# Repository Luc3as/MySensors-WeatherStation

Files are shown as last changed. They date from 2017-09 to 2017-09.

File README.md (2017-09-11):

# MySensors-WeatherStation
Weather station based on arduino and MySensors

It is battery operated, solar pannel charged, wirelessly communicating weather station which can measure temperature, humidity, moisture,  atmospheric pressure and rain.

Body of weather station is partly 3d printed and each radiation shield floor is made of pot plate you can get in garden supplies.
There are 3D printables files, as well as source files from Autodesk Invetor if you need to adjust some parts.

## Final installation

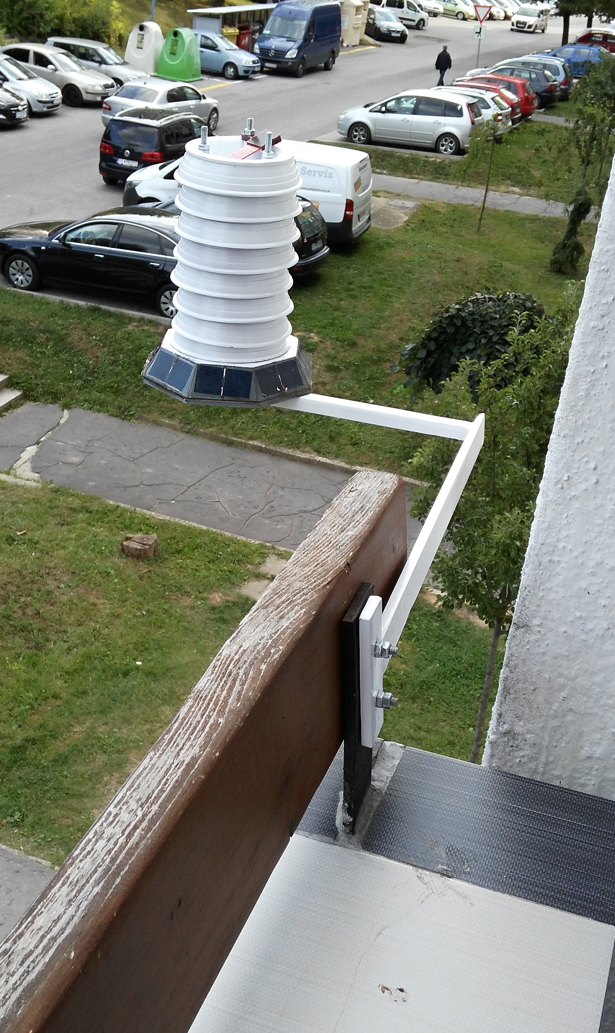
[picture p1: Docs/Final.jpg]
Final installation


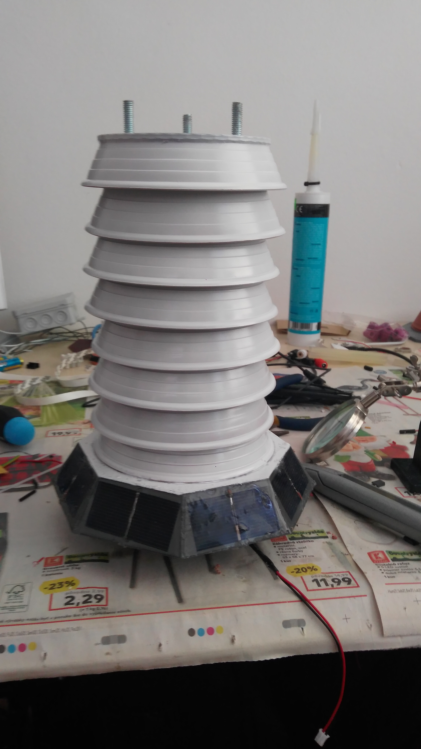
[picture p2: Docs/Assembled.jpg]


## From protype to functional weather station

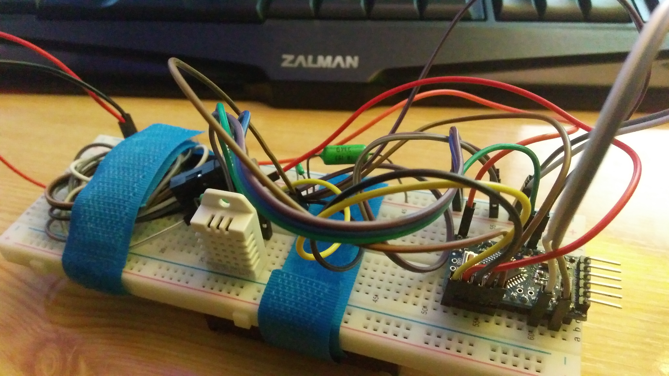
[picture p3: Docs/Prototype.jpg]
Prototype


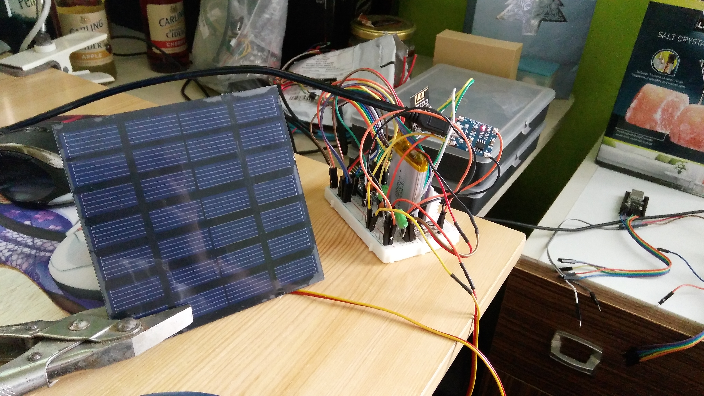
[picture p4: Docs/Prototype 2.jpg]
Prototype 2


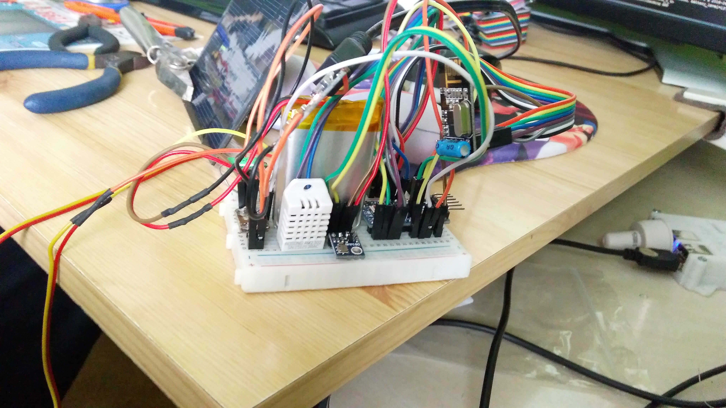
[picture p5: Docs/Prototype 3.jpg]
Prototype3


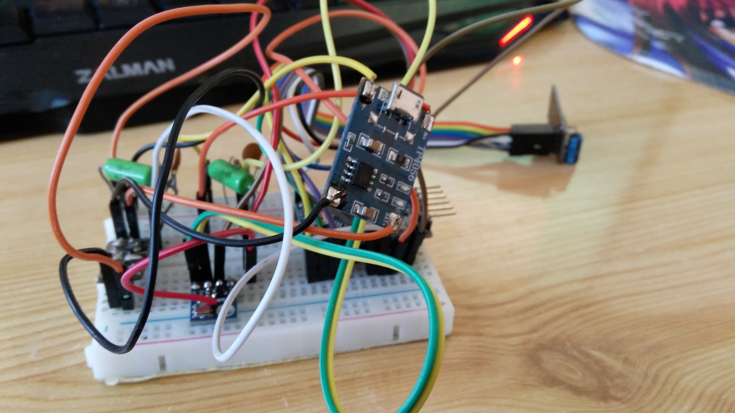
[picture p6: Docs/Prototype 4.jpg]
Prototype 4


I started with breadboard, attached arduino pro mini, NRF24 some DHT22 temp meter and do some basic code.
Later I added solar pannel, with charging contoller, LiPo battery, and voltage level convertor to do voltage measurement of battery and solar pannel.

Later I replaced DHT22 sensor with Si 7021 which provides better performance and reliability by my experience.

## PCBs

Prototype was working so I started designing PCBS in Fritzing, you can find source file in PCB folder. About month from ordering at chinese website, manufactured PCBs arrived.

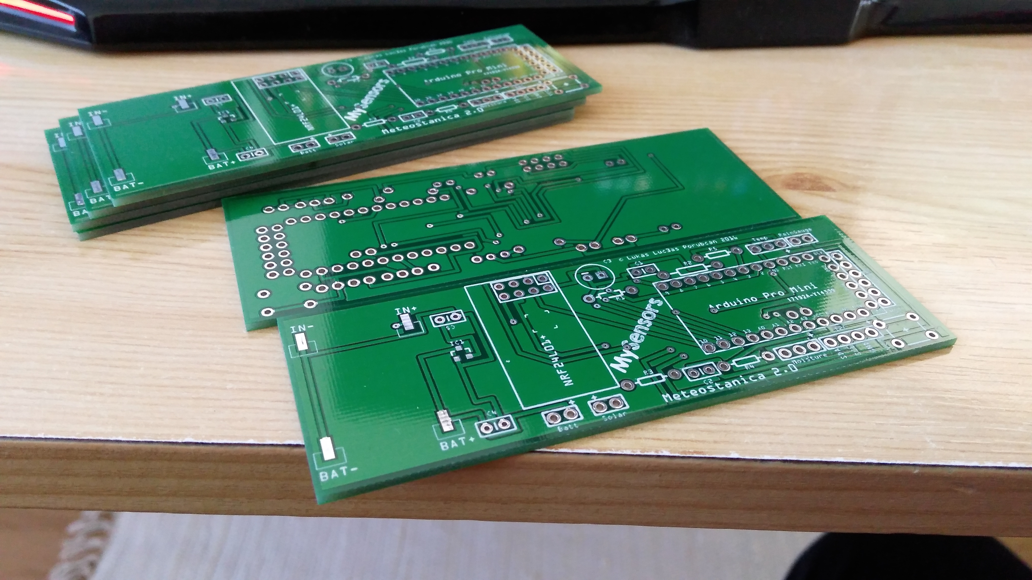
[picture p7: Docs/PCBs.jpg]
PCBs


I was very curious if my design will work so I started assembly of PCB very quickly.

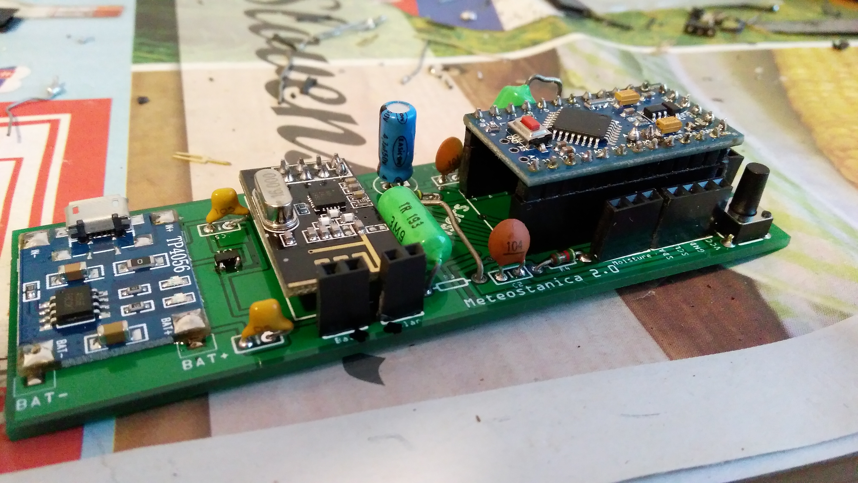
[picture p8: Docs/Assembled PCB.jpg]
PCBs assembled


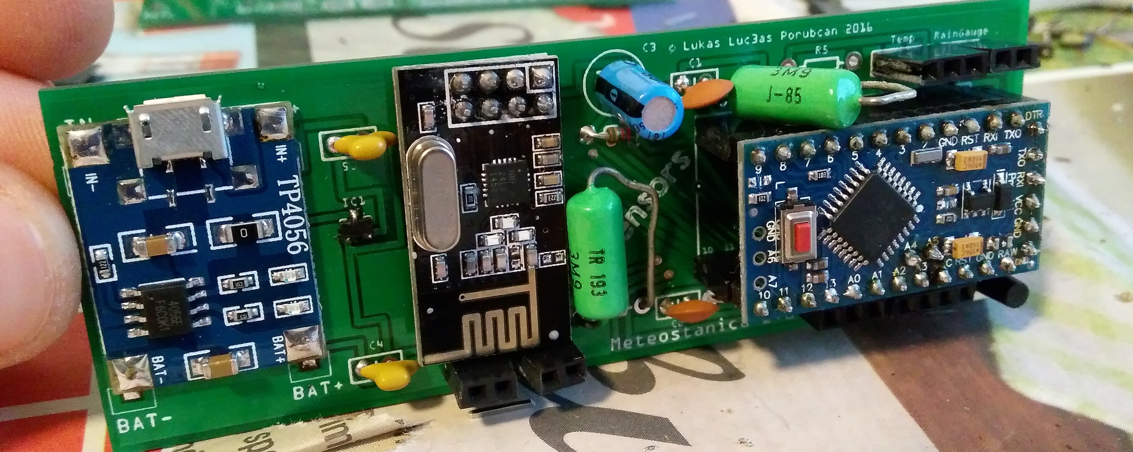
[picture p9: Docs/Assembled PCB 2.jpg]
PCBs assembled 2


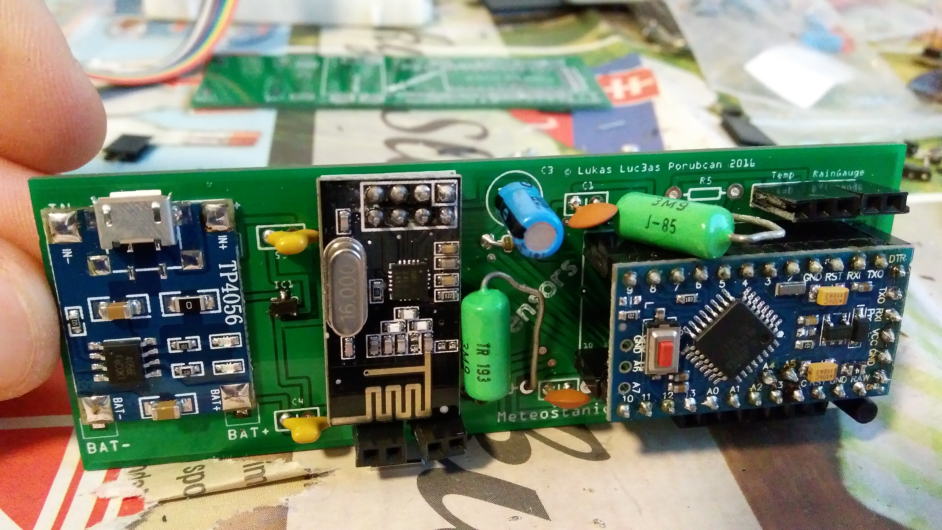
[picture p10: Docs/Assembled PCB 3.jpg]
PCBs assembled 3


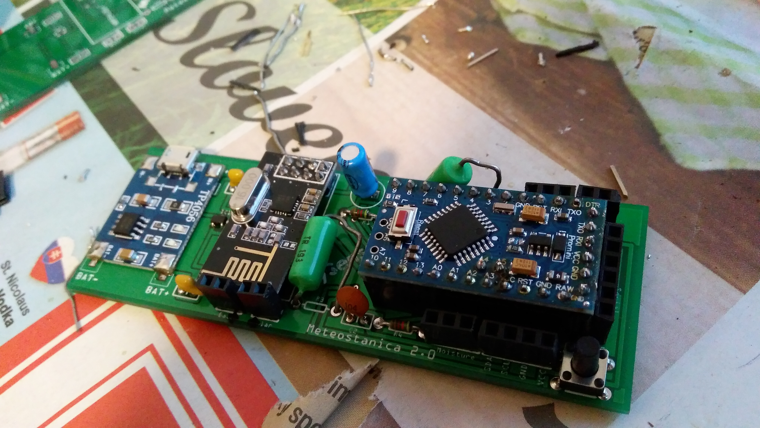
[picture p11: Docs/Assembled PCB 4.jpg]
PCBs assembled 4


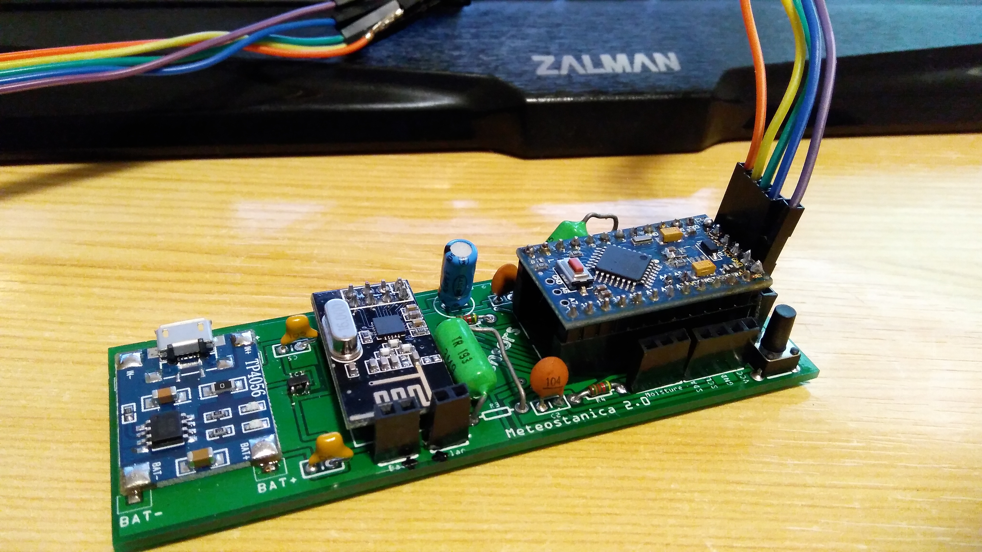
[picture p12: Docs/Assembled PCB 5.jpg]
PCBs assembled 5


## Building the body

I printed the base of weather station and started to assembly solar pannels which are glued in clear epoxy resin. I have to lay each side of base absolutely flat, put panel with wires in little window on sides, and after puoring the epoxy resin wait till it harden.
In next designs I would choose another path and probably made each pannel shell separate so I can glue all panels at once and when they will be hard and more durable I would glue it to the base.

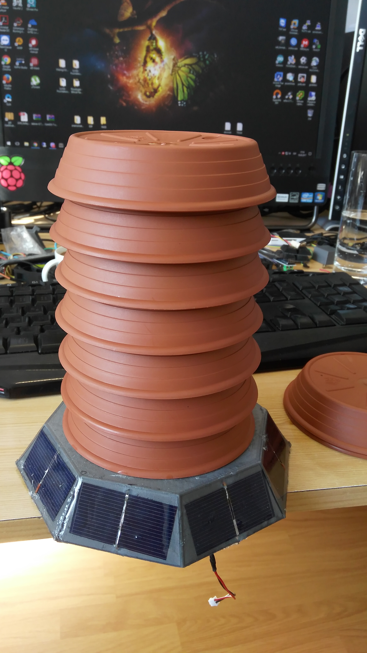
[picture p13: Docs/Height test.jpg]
Heigh test of stands


All the pannels are connected in serie, providing about 4,5V in direct sunlight, which is enough to charge the battery every day.

For holding all together there are 3x 6mm rods which goes through every floor and are secured with nuts. All holes are secured with silicon providing little of waterproofness mainly for sensors and for base where electronics is localed.

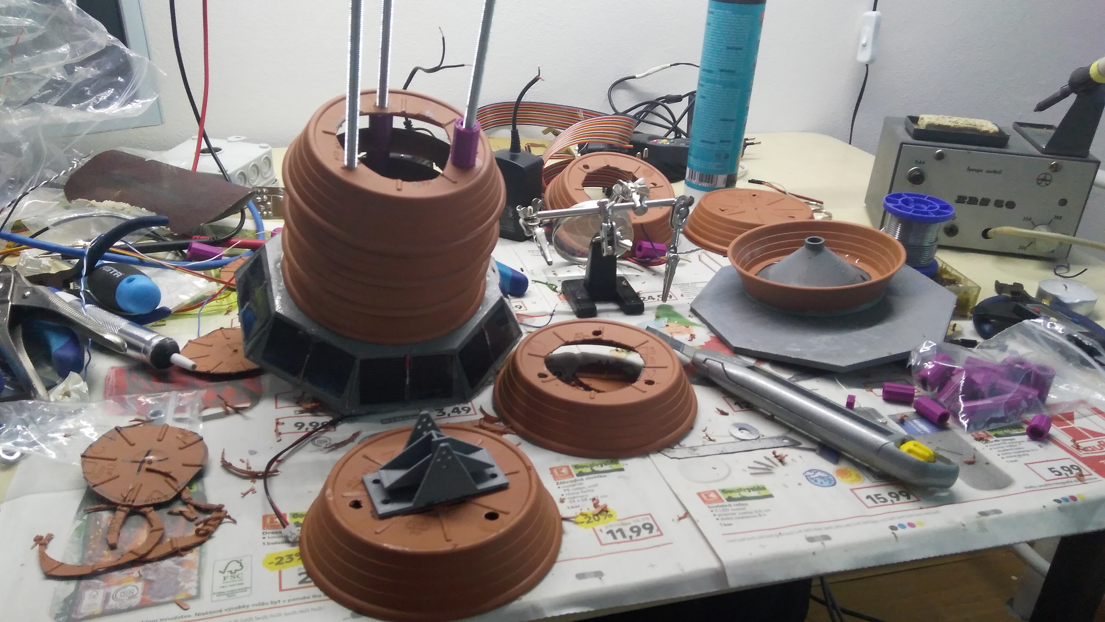
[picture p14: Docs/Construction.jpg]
Construction


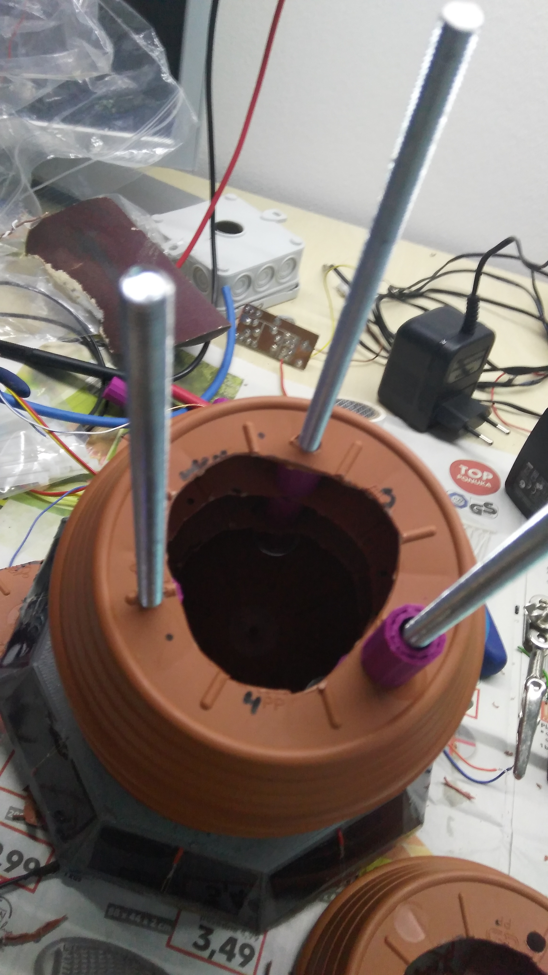
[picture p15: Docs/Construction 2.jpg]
Construction


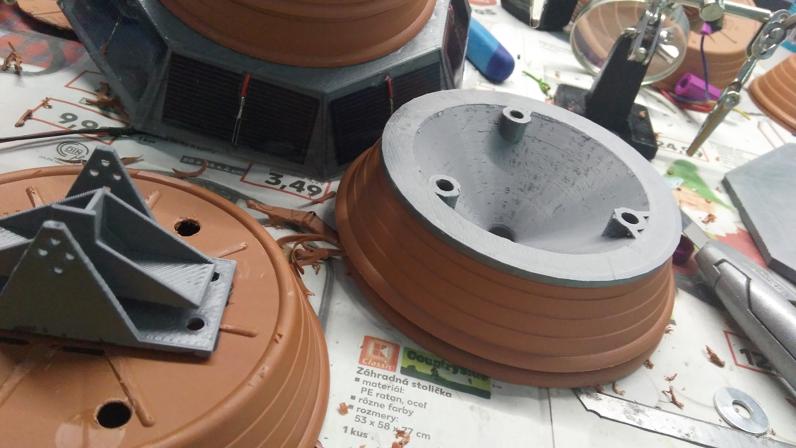
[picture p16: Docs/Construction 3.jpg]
Construction


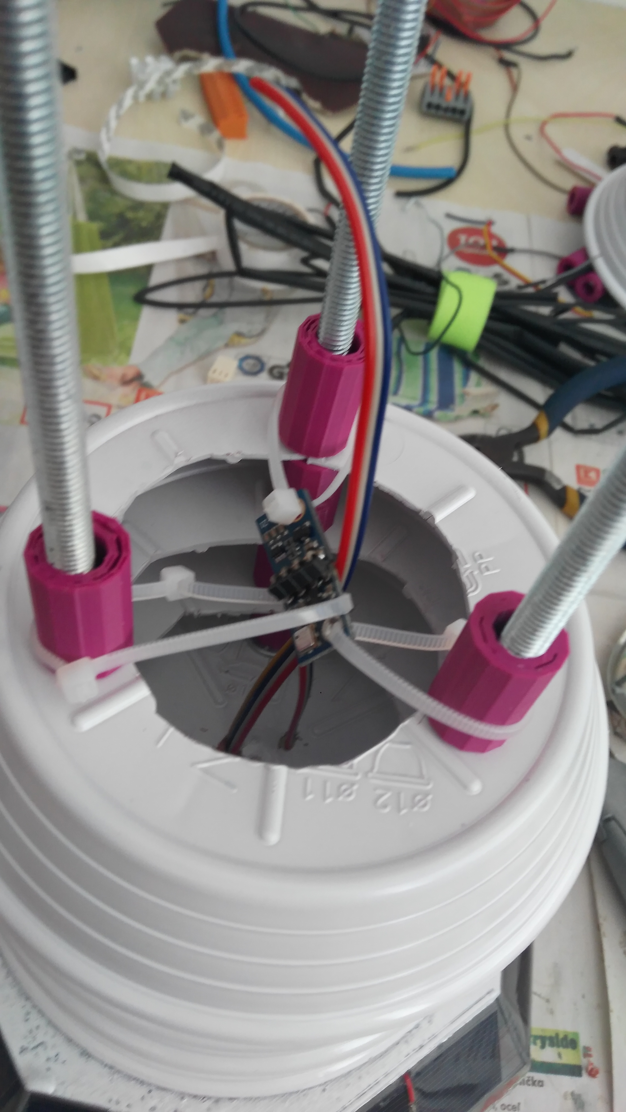
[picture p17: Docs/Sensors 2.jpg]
Sensors in the middle


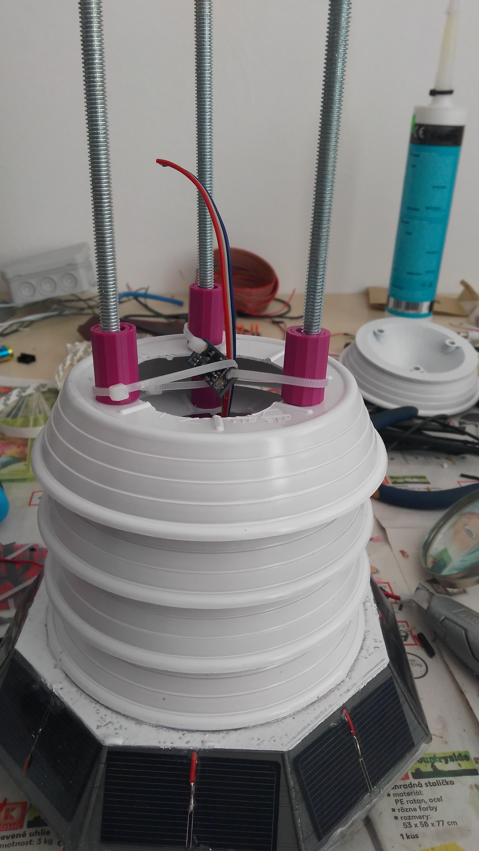
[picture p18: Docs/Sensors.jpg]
Sensors in the middle


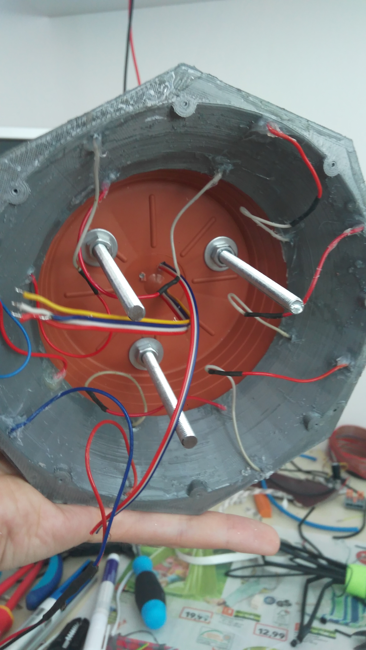
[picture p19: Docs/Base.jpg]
Base


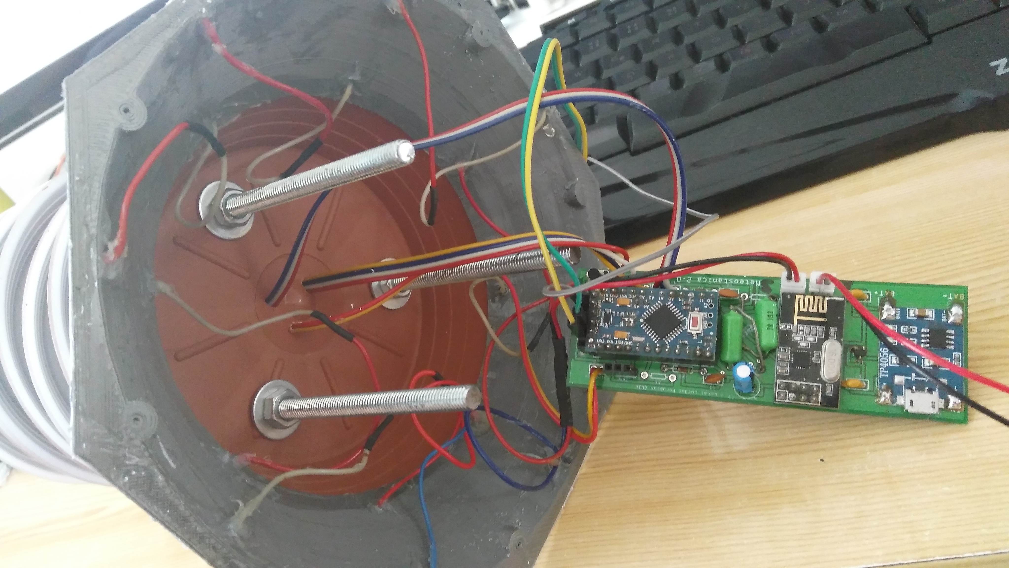
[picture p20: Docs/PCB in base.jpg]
PCB in base


## Rain bucket

To provide measurement of rain fall, there is 3d printed rain bucket with reed switch and neodyme magnet glued to it, and it is placed under the cone top where is hole at the bottom.

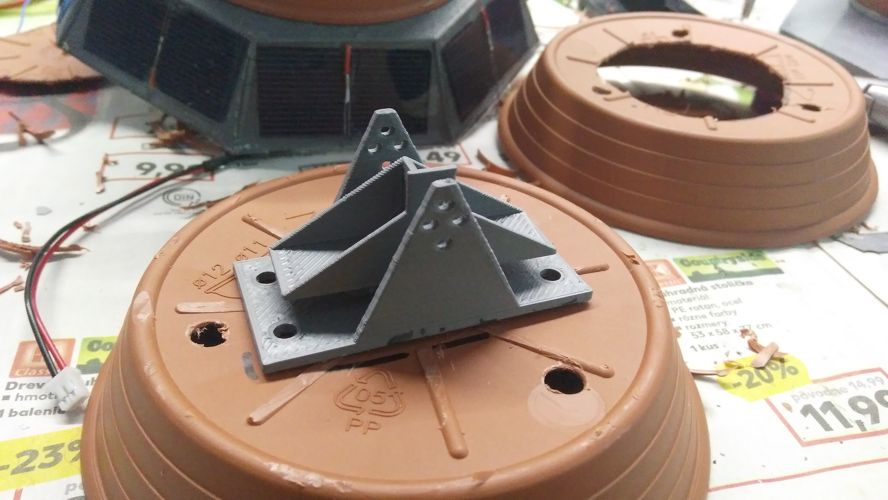
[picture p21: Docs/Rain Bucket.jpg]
Rain bucket


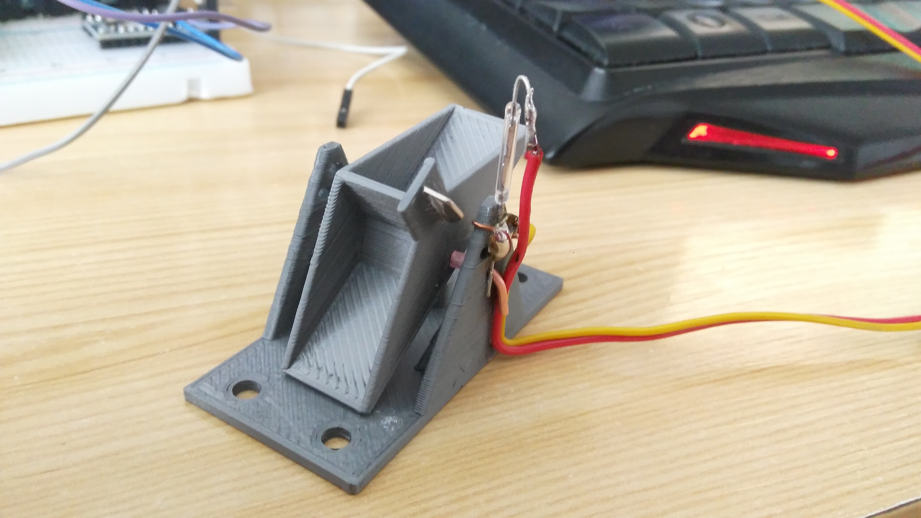
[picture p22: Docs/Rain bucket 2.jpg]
Rain bucket 2


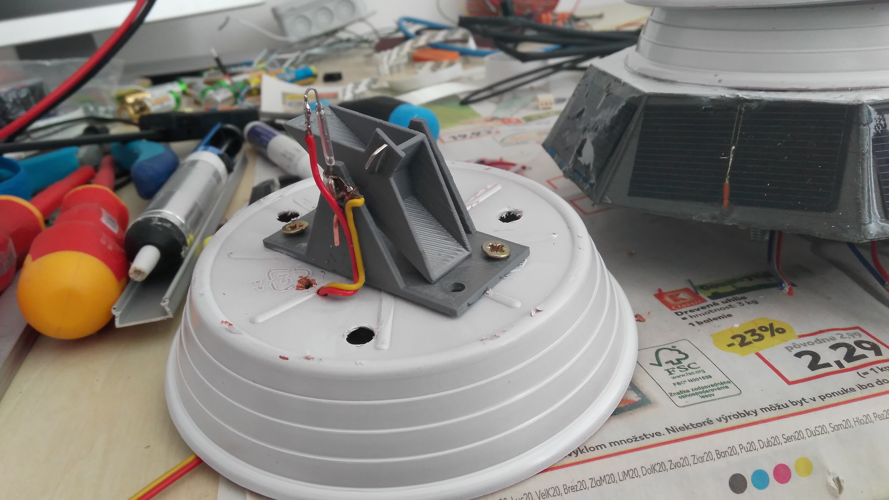
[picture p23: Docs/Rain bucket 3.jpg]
Rain bucket 3


## Overall look

There is moisture meter holder missing I added it later.

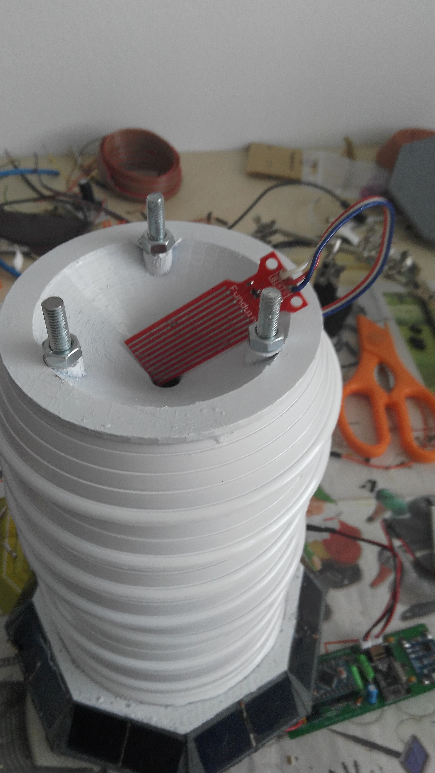
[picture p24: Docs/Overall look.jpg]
Overall look


## Configuration

There are some configuration steps needed such as adjusting the voltage divider ratio to do measurement of voltages properly. I tried to made code self explaining.

    #define MY_NODE_ID 5  
    #define CALIBRATE_FACTOR 15 // amount of rain per rain bucket tip e.g. 5 is .05mm
    int BATTERY_SENSE_PIN = A2;  // select the input pin for the battery sense point
    int SOLAR_SENSE_PIN = A3;  // select the input pin for the solar panel sense point
    int MOISTURE_SENSE_PIN = A1;  // select the input pin for the soil mosture sensor
    int TIP_SENSOR_PIN = 3; // input pin where reed switch or hall effect sensor is attached
    int SEND_DATA_EVERY = 5 ; // send data to controller every n minutes

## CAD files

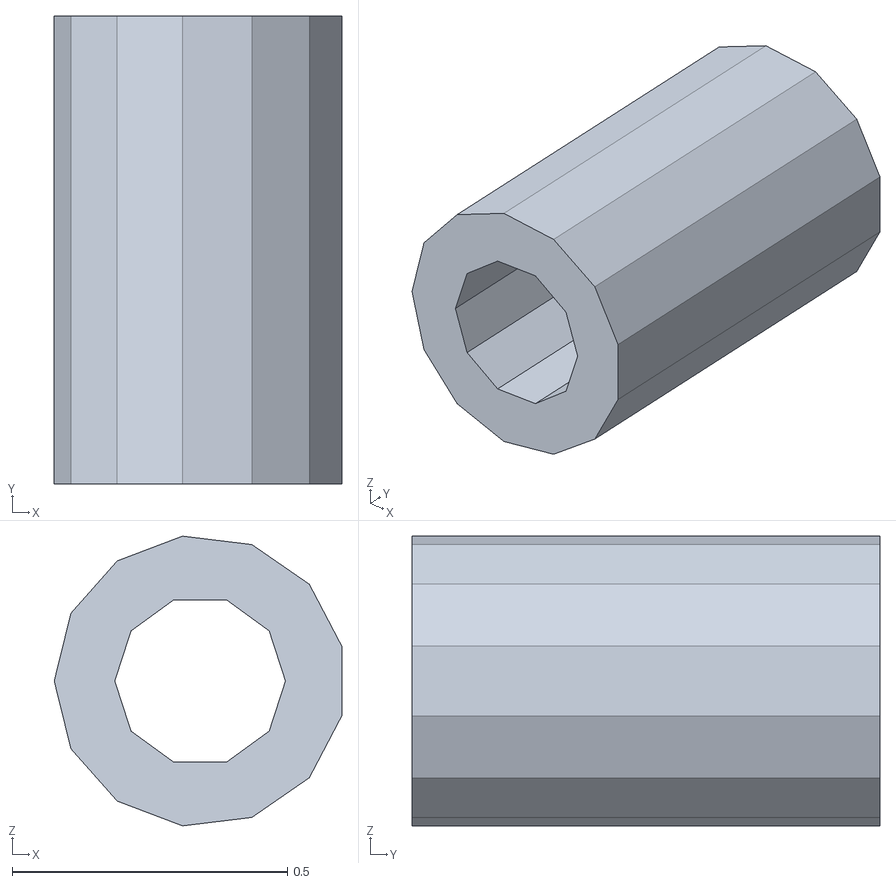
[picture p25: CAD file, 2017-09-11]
3D print/stand.stl
0.522 x 0.85 x 0.526

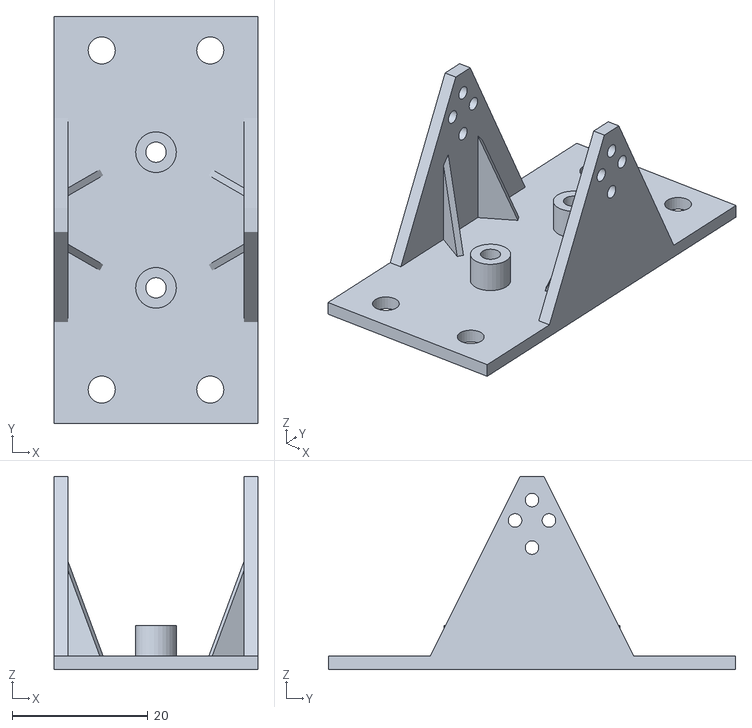
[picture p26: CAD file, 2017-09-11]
3D print/rain_base2.stl
30.0 x 60.0 x 28.5

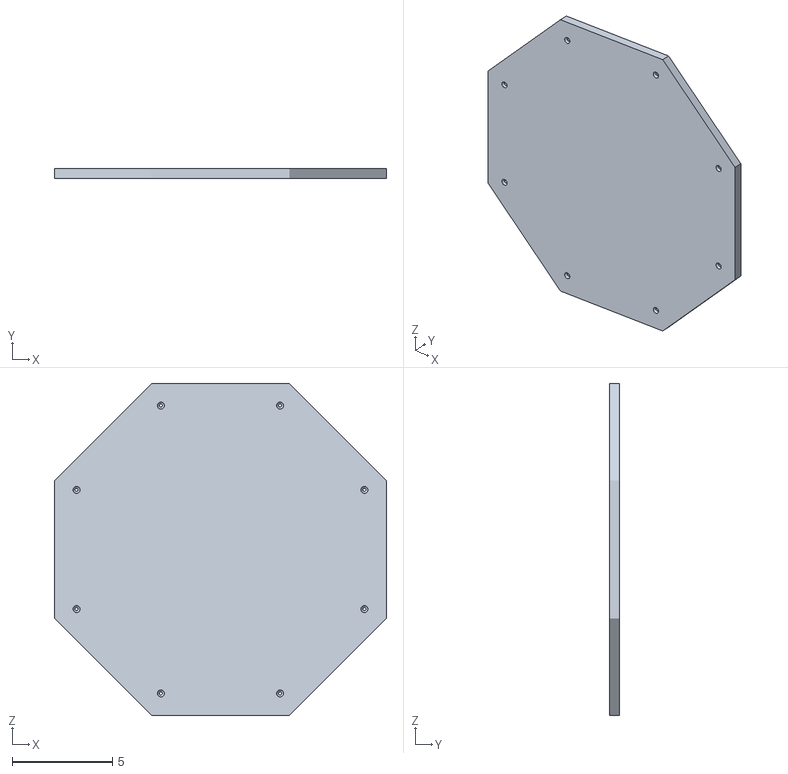
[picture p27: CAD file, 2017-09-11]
3D print/radiation shield cover.stl
16.5 x 0.5 x 16.5

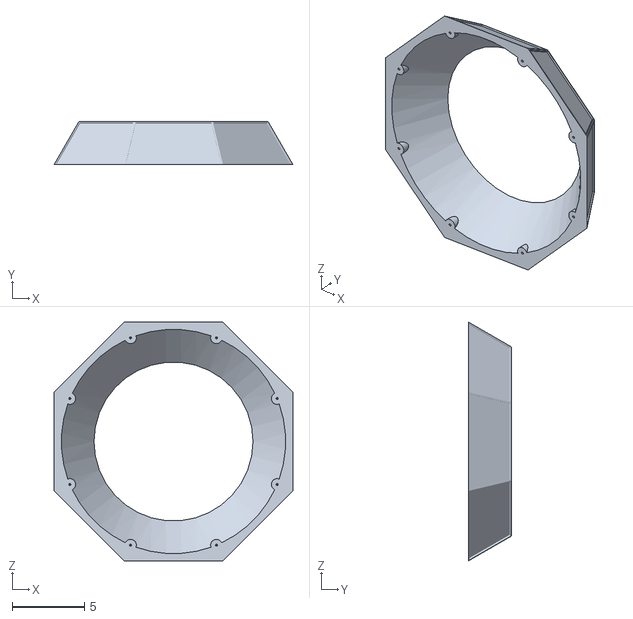
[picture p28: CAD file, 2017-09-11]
3D print/radiation shield base.stl
16.5 x 3.00 x 16.5

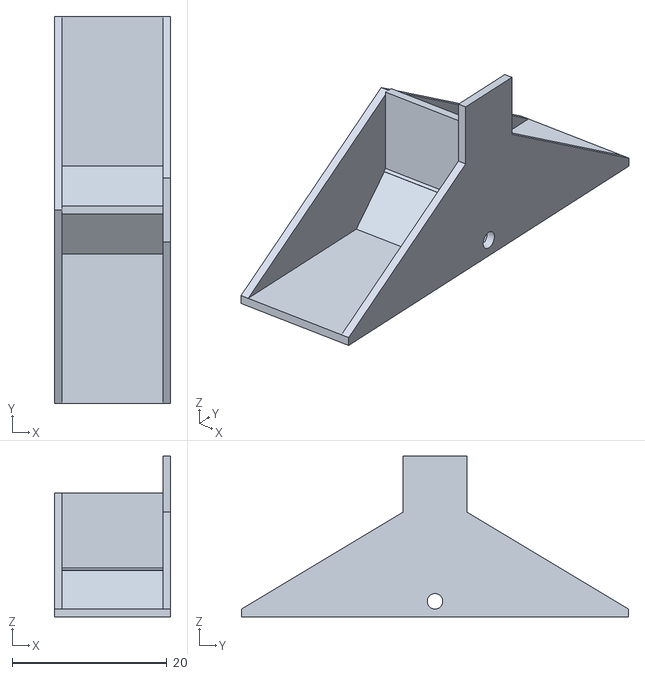
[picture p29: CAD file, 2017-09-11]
3D print/water-bucket.stl
15.0 x 50.0 x 20.8

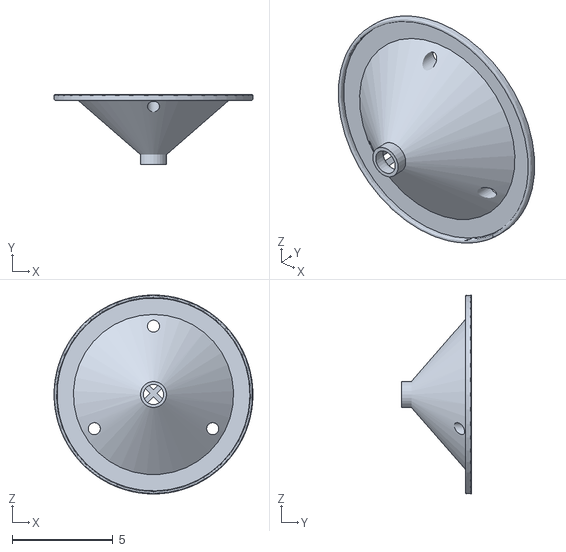
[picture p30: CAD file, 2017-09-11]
3D print/meteostanica lievik.stl
9.90 x 3.50 x 9.90

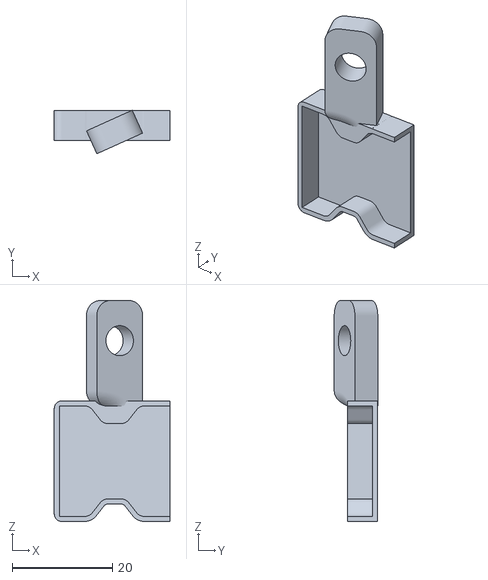
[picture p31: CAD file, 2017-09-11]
3D print/moisture meter holder.stl
23.0 x 8.67 x 44.0

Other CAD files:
3D print/meteostanica lievik.ipt
3D print/moisture meter holder.ipt
3D print/radiation shield base.ipt
3D print/radiation shield cover.ipt
3D print/stand.ipt

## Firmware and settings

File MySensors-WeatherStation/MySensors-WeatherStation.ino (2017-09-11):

#include <Arduino.h>

/**
 * The MySensors Arduino library handles the wireless radio link and protocol
 * between your home built sensors/actuators and HA controller of choice.
 * The sensors forms a self healing radio network with optional repeaters. Each
 * repeater and gateway builds a routing tables in EEPROM which keeps track of the
 * network topology allowing messages to be routed to nodes.
 *
 * Created by Henrik Ekblad <henrik.ekblad@mysensors.org>
 * Copyright (C) 2013-2015 Sensnology AB
 * Full contributor list: https://github.com/mysensors/Arduino/graphs/contributors
 *
 * Documentation: http://www.mysensors.org
 * Support Forum: http://forum.mysensors.org
 *
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
 ******************************
 *
 */
// Enable MY_DEBUG flag for MY_DEBUG prints. This will add a lot to the size of the final sketch but good
// to see what is actually is happening when developing
#define MY_DEBUG


// Enable and select radio type attached
#define MY_RADIO_NRF24

#define MY_NODE_ID 5
#define CHILD_ID_HUM 0
#define CHILD_ID_TEMP 1
#define CHILD_ID_BARO 2
#define CHILD_ID_FOREC 3
#define CHILD_ID_VBATT 4
#define CHILD_ID_VSOLAR 5
#define CHILD_ID_MOISTURE 6
#define CHILD_ID_RAIN_LOG 7  // Keeps track of accumulated rainfall
#define CHILD_ID_RAIN_RATE 8 // rain rate
//#define CHILD_ID_TRIPPED_INDICATOR 8  // Indicates Tripped when rain detected


#include <SPI.h>
#include <MySensors.h>
#include <Wire.h>
#include <SI7021.h>
#include <Adafruit_BMP085.h>
#include <math.h>
#include <TimeLib.h>


#define CALIBRATE_FACTOR 15 // amount of rain per rain bucket tip e.g. 5 is .05mm
#define EEPROM_BUFFER_LOCATION 0  // location of the EEPROM circular buffer
#define E_BUFFER_LENGTH 240
#define RAIN_BUCKET_SIZE 120
int BATTERY_SENSE_PIN = A2;  // select the input pin for the battery sense point
int SOLAR_SENSE_PIN = A3;  // select the input pin for the solar panel sense point
int MOISTURE_SENSE_PIN = A1;  // select the input pin for the soil mosture sensor
int TIP_SENSOR_PIN = 3; // input pin where reed switch or hall effect sensor is attached
int eepromIndex;
#define WAIT_BETWEEN_SEND 200  // time between sending messages, allowing to clear buffers on radio and GW

// Constants
#define BATTERY_MAX_VOLTAGE 4.21 // V, nominal voltage at battery for powering up device
#define BATTERY_MIN_VOLTAGE 2.9 // V, minimal voltage at which sensor still works
unsigned long SLEEP_TIME = 60000UL; // Sleep time between reads (in milliseconds)
int SEND_DATA_EVERY = 1 ; // send data to controller every n minutes
const int ALTITUDE = 242; // <-- adapt this value to your own location's altitude.

const char *weather[] = { "stable", "sunny", "cloudy", "unstable", "thunderstorm", "unknown" };
enum FORECAST
{
  STABLE = 0,     // "Stable Weather Pattern"
  SUNNY = 1,      // "Slowly rising Good Weather", "Clear/Sunny "
  CLOUDY = 2,     // "Slowly falling L-Pressure ", "Cloudy/Rain "
  UNSTABLE = 3,   // "Quickly rising H-Press",     "Not Stable"
  THUNDERSTORM = 4, // "Quickly falling L-Press",    "Thunderstorm"
  UNKNOWN = 5     // "Unknown (More Time needed)
};

const unsigned long oneHour = 3600;
unsigned long lastTipTime;
unsigned long lastTipTimeRTC;
unsigned long thisTipTime;
unsigned long lastRainTime = 0; //Used for rainRate calculation
unsigned int rainBucket [RAIN_BUCKET_SIZE] ; /* 24 hours x 5 Days = 120 hours */
unsigned int rainRate = 0;
uint8_t rainWindow = 72;         //default rain window in hours.  Will be overwritten with msgTrippedVar1.
int wasTippedBuffer = 0;
int rainSensorThreshold = 50; //default rain sensor sensitivity in hundredths.  Will be overwritten with msgTrippedVar2.
uint8_t state = 0;
uint8_t oldState = 2; //Setting the default to something other than 1 or 0
unsigned int lastRainRate = 0;
int lastMeasure = 0;
bool gotTime = false;
uint8_t lastHour = 0;
uint8_t currentHour;
int lulaby = 0;
int index = 0;
float lastPressureAvg = 0;
float change = 0;
float pressure = 0;

Adafruit_BMP085 bmp;
float lastTemperature;
float lastHumidity;
boolean metric = true;
int oldBatteryPcnt = 0;
float oldVBatt = 0;
float oldVSolar = 0;
int oldMoisture = 0;
float lastPressure = -1;
int lastForecast = -1;
int forecast = -1;

const int LAST_SAMPLES_COUNT = 5;
float lastPressureSamples[LAST_SAMPLES_COUNT];

// this CONVERSION_FACTOR is used to convert from Pa to kPa in forecast algorithm
// get kPa/h be dividing hPa by 10
#define CONVERSION_FACTOR (1.0/10.0)

SI7021 sisensor;

int minuteCount = 0;
int sendCount = -1;
bool firstRound = true;
// average value is used in forecast algorithm.
float pressureAvg;
// average after 2 hours is used as reference value for the next iteration.
float pressureAvg2;
float dP_dt;

MyMessage msgHumidity(CHILD_ID_HUM, V_HUM);
MyMessage msgTemperature(CHILD_ID_TEMP, V_TEMP);
MyMessage pressureMsg(CHILD_ID_BARO, V_PRESSURE);
MyMessage forecastMsg(CHILD_ID_FOREC, V_FORECAST);
MyMessage msgPrefix(CHILD_ID_BARO, V_UNIT_PREFIX);  // Custom unit message.
MyMessage msgVBatt(CHILD_ID_VBATT, V_VOLTAGE);
MyMessage msgVSolar(CHILD_ID_VSOLAR, V_VOLTAGE);
MyMessage msgMoisture(CHILD_ID_MOISTURE, V_LEVEL);
MyMessage msgMoisturePrefix(CHILD_ID_MOISTURE, V_UNIT_PREFIX);  // Custom unit message.
MyMessage msgRainRate(CHILD_ID_RAIN_RATE, V_RAINRATE);
MyMessage msgRain(CHILD_ID_RAIN_LOG, V_RAIN);
MyMessage msgPrefix1(CHILD_ID_RAIN_LOG, V_UNIT_PREFIX);  // Custom unit message.
MyMessage msgRainVAR1(CHILD_ID_RAIN_LOG, V_VAR1);
MyMessage msgRainVAR2(CHILD_ID_RAIN_LOG, V_VAR2);
MyMessage msgRainVAR3(CHILD_ID_RAIN_LOG, V_VAR3);
MyMessage msgRainVAR4(CHILD_ID_RAIN_LOG, V_VAR4);
MyMessage msgRainVAR5(CHILD_ID_RAIN_LOG, V_VAR5);
//MyMessage msgTripped(CHILD_ID_TRIPPED_INDICATOR, V_TRIPPED);
//MyMessage msgTrippedVar1(CHILD_ID_TRIPPED_INDICATOR, V_VAR1);
//MyMessage msgTrippedVar2(CHILD_ID_TRIPPED_INDICATOR, V_VAR2);


void presentation()
{
  // Send the Sketch Version Information to the Gateway
  sendSketchInfo("Weather_Station", "2.1");

  // Register all sensors to gw (they will be created as child devices)
  present(CHILD_ID_HUM, S_HUM);
  wait(WAIT_BETWEEN_SEND, C_INTERNAL, I_TIME); // Wait before next message send
  present(CHILD_ID_TEMP, S_TEMP);
  wait(WAIT_BETWEEN_SEND, C_INTERNAL, I_TIME); // Wait before next message send
  present(CHILD_ID_BARO, S_BARO);
  wait(WAIT_BETWEEN_SEND, C_INTERNAL, I_TIME); // Wait before next message send
  present(CHILD_ID_FOREC, S_BARO);
  wait(WAIT_BETWEEN_SEND, C_INTERNAL, I_TIME); // Wait before next message send
  present(CHILD_ID_VBATT, S_MULTIMETER);
  wait(WAIT_BETWEEN_SEND, C_INTERNAL, I_TIME); // Wait before next message send
  present(CHILD_ID_VSOLAR, S_MULTIMETER);
  wait(WAIT_BETWEEN_SEND, C_INTERNAL, I_TIME); // Wait before next message send
  present(CHILD_ID_MOISTURE, S_MOISTURE);
  wait(WAIT_BETWEEN_SEND, C_INTERNAL, I_TIME); // Wait before next message send
  present(CHILD_ID_RAIN_LOG, S_RAIN);
  wait(WAIT_BETWEEN_SEND, C_INTERNAL, I_TIME); // Wait before next message send
  present(CHILD_ID_RAIN_RATE, S_RAIN);

  //present(CHILD_ID_TRIPPED_INDICATOR, S_MOTION);
  #ifdef MY_DEBUG
    Serial.println(F("Presentation complete"));
  #endif
}

// +++++++++++++++++++++++++++++++++++++++++++++++++++++++++++++++++++++++++++++
//
// SETUP
//
// +++++++++++++++++++++++++++++++++++++++++++++++++++++++++++++++++++++++++++++

void setup()
{
  // use the 1.1 V internal reference for voltage measurement
  #if defined(__AVR_ATmega2560__)
     analogReference(INTERNAL1V1);
  #else
     analogReference(INTERNAL);
  #endif

  // setup BMP sensor
  if (!bmp.begin())
  {
    Serial.println(F("Could not find a valid BMP180 sensor, check wiring!"));
  }
  metric = getControllerConfig().isMetric;

  // setup SI7027 sensor
  if (!sisensor.begin())
  {
    Serial.println(F("Could not find a valid SI7021 sensor, check wiring!"));
  }

  // Set up the IO
  pinMode(TIP_SENSOR_PIN, INPUT_PULLUP);
  //attachInterrupt (digitalPinToInterrupt(TIP_SENSOR_PIN), sensorTipped, FALLING);  // depending on location of the hall effect sensor may need CHANGE

  //retrieve from EEPROM stored values on a power cycle.
  bool isDataOnEeprom = false;
  for (int i = 0; i < E_BUFFER_LENGTH; i++)
  {
    uint8_t locator = loadState(EEPROM_BUFFER_LOCATION + i);
    if (locator == 0xFE)  // found the EEPROM circular buffer index
    {
      eepromIndex = EEPROM_BUFFER_LOCATION + i;
      #ifdef MY_DEBUG
        Serial.print(F("EEPROM Index "));
        Serial.println(eepromIndex);
      #endif
      //Now that we have the buffer index let's populate the rainBucket[] with data from eeprom
      loadRainArray(eepromIndex);
      isDataOnEeprom = true;
      break;
    }
  }
  // Added for the first time it is run on a new Arduino
  if (!isDataOnEeprom)
  {
    #ifdef MY_DEBUG
      Serial.print(F("I didn't find valid EEPROM Index, so I'm writing one to location 0"));
    #endif
    eepromIndex = EEPROM_BUFFER_LOCATION;
    saveState(eepromIndex, 0xFE);
    saveState(eepromIndex + 1, 0xFE);
    //then I will clear out any bad data
    for (int i = 2; i <= E_BUFFER_LENGTH; i++)
    {
      saveState(i, 0x00);
    }
  }
  lastTipTime = millis();
  lastTipTimeRTC = now();
  //
  //request(CHILD_ID_TRIPPED_INDICATOR, V_VAR1);
  //request(CHILD_ID_TRIPPED_INDICATOR, V_VAR2);
  //

  transmitRainData(); //Setup complete send any data loaded from eeprom to gateway

} // END Setup


// +++++++++++++++++++++++++++++++++++++++++++++++++++++++++++++++++++++++++++++
// LOOP
// +++++++++++++++++++++++++++++++++++++++++++++++++++++++++++++++++++++++++++++


void loop() {
  #ifdef MY_DEBUG
    Serial.print(F("Wakeup reason : "));
    if (lulaby == 0) {
      Serial.println(F("first wakeup."));
    } else if (lulaby == 1 ) {
      Serial.println(F("interrupt 1."));
    } else {
      Serial.println(F("sleep timer."));
    }
  #endif

  if (lulaby == 1) // running when interrupt wakes up by raingauge tip
  {
    thisTipTime = millis();
    //if (thisTipTime - lastTipTime > 50UL) { // debounce raingauge
      rainBucket[0] += CALIBRATE_FACTOR; // adds CALIBRATE_FACTOR hundredths of unit each tip
      wasTippedBuffer++;
      #ifdef MY_DEBUG
        Serial.println(F("It is raining..."));
      #endif
    //}
    lastTipTime = thisTipTime;
    lastTipTimeRTC = now();
    if (lastRainTime == 0) {
      lastRainTime = now() ;
    }
    setTime(now()+2); // add time when it is awaken now

  } else {  // running when node woke up from timer

    if (gotTime == true) {  // time is set, move time forward with SLEEP_TIME
      #ifdef MY_DEBUG
        Serial.println(F("Adding SLEEP_TIME to actual time"));
      #endif
      setTime(now()+(SLEEP_TIME / 1000));
    } else {  // time is not set, request new time
      #ifdef MY_DEBUG
        Serial.println(F("Requesting time"));
      #endif
      requestTime();
    }

  #ifdef MY_DEBUG
    // print current time we have from controller
    char currentTime[10];
    sprintf(currentTime, "%d:%d:%d",hour(),minute(),second());
    Serial.print(F("Current time on arduino  "));
    Serial.println(currentTime);
  #endif

  // increment sendCount every minute
  sendCount ++ ;
  if (sendCount >= SEND_DATA_EVERY || sendCount <= 0) { // send data every n minute
    sendCount = 0 ;

    #ifdef MY_DEBUG
      Serial.println(F("Measurring everything"));
    #endif

    // get the battery Voltage
    int batteryRead = analogRead(BATTERY_SENSE_PIN);

    // voltage divider across battery and using internal ADC ref voltage of 1.1V
    // Sense point is bypassed with 0.1 uF cap to reduce noise at that point
    // 3.94 M ohm a 421 k ohm , ref 1,1v Vmax at battery 11.395V , use http://www.raltron.com/cust/tools/voltage_divider.asp for max V calculation
    // 11.395/1023 = Volts per bit = 0,01113880742913000977517106549365
    float batteryV  = batteryRead * 0.01113880742913000977517106549365;
    int batteryPcnt = ((batteryV - BATTERY_MIN_VOLTAGE) / (BATTERY_MAX_VOLTAGE - BATTERY_MIN_VOLTAGE)) * 100 ;
    if (batteryPcnt <= 0 ) {
      batteryPcnt = 0;
    }

    #ifdef MY_DEBUG
      Serial.print(F("Analog read battery: "));
      Serial.println(batteryRead);

      Serial.print(F("Battery Voltage: "));
      Serial.print(batteryV);
      Serial.println(" V");

      Serial.print(F("Battery percent: "));
      Serial.print(batteryPcnt);
      Serial.println(F(" %"));
    #endif

    // send battery %
    if (oldBatteryPcnt != batteryPcnt) {
      sendBatteryLevel(batteryPcnt);
      wait(WAIT_BETWEEN_SEND, C_INTERNAL, I_TIME); // Wait before next message send
      oldBatteryPcnt = batteryPcnt;
    }

    // send battery voltage
    if (oldVBatt != batteryV) {
      send(msgVBatt.set(batteryV, 2));
      wait(WAIT_BETWEEN_SEND, C_INTERNAL, I_TIME); // Wait before next message send
      oldVBatt = batteryV;
    }

    // get the Solar pannel Voltage
    int solarReading = analogRead(SOLAR_SENSE_PIN);

    // voltage divider across battery and using internal ADC ref voltage of 1.1V
    // Sense point is bypassed with 0.1 uF cap to reduce noise at that point
    // 3.94 M ohm a 421 k ohm , ref 1,1v Vmax at battery 11.395V , use http://www.raltron.com/cust/tools/voltage_divider.asp for max v calculation
    // 11.395/1023 = Volts per bit = 0,01113880742913000977517106549365
    float solarV  = solarReading * 0.01113880742913000977517106549365;

    #ifdef MY_DEBUG
      Serial.print(F("Analog read solar pannel: "));
      Serial.println(solarReading);

      Serial.print(F("Solar pannel Voltage: "));
      Serial.print(solarV);
      Serial.println(F(" V"));
    #endif

    // send solar pannel voltage
    if (oldVSolar != solarV) {
      send(msgVSolar.set(solarV, 2));
      wait(WAIT_BETWEEN_SEND, C_INTERNAL, I_TIME); // Wait before next message send
      oldVSolar = solarV;
    }

    // BMP180 sensor
    // get the pressure reading
    pressure = 0 ;
    bmp.readTemperature();
    wait(1000, C_INTERNAL, I_TIME);
    pressure = bmp.readSealevelPressure(ALTITUDE) / 100.0;

    forecast = sample(pressure);

    #ifdef MY_DEBUG
      Serial.print(F("Pressure = "));
      Serial.print(pressure);
      Serial.println(F(" hPa"));
      Serial.print(F("Forecast = "));
      Serial.println(weather[forecast]);

      Serial.print(F("Temperature BMP = "));
      Serial.print(bmp.readTemperature());
      Serial.println(F(" *C"));

      Serial.print(F("Pressure = "));
      Serial.print(bmp.readPressure());
      Serial.println(F(" Pa"));

      // Calculate altitude assuming 'standard' barometric
      // pressure of 1013.25 millibar = 101325 Pascal
      Serial.print(F("Altitude = "));
      Serial.print(bmp.readAltitude());
      Serial.println(F(" meters"));

    // you can get a more precise measurement of altitude
    // if you know the current sea level pressure which will
    // vary with weather and such. If it is 1015 millibars
    // that is equal to 101500 Pascals.
      Serial.print(F("Real altitude = "));
      Serial.print(bmp.readAltitude(101700));
      Serial.println(F(" meters"));
    #endif

    // send pressure reading
    if (pressure != lastPressure)
    {
      send(pressureMsg.set(pressure, 1));
      wait(WAIT_BETWEEN_SEND, C_INTERNAL, I_TIME); // Wait before next message send
      send(msgPrefix.set("hPa"));  // Set custom unit.
      wait(WAIT_BETWEEN_SEND, C_INTERNAL, I_TIME); // Wait before next message send
      lastPressure = pressure;
    }

    // send forecast reading
    if (forecast != lastForecast)
    {
      send(forecastMsg.set(weather[forecast]));
      wait(WAIT_BETWEEN_SEND, C_INTERNAL, I_TIME); // Wait before next message send
      lastForecast = forecast;
    }

    // get the moisture reading
    int moistureRead = analogRead(MOISTURE_SENSE_PIN);

    int moisturePcnt = map(moistureRead, 0, 1024, 0, 101);

    #ifdef MY_DEBUG
      Serial.print(F("Analog read moisture: "));
      Serial.println(moistureRead);

      Serial.print(F("Moisture percent: "));
      Serial.print(moisturePcnt);
      Serial.println(F(" %"));
    #endif

    // send moisture %
    if (moisturePcnt != oldMoisture) {
      send(msgMoisture.set(moisturePcnt, 0));
      wait(WAIT_BETWEEN_SEND, C_INTERNAL, I_TIME); // Wait before next message send
      send(msgMoisturePrefix.set("%"));  // Set custom unit.
      wait(WAIT_BETWEEN_SEND, C_INTERNAL, I_TIME); // Wait before next message send
      oldMoisture = moisturePcnt;
    }

    // SI7027 Sensor
    // temperature
    float temperature = sisensor.getCelsiusHundredths();
    temperature = temperature /100 ;

    // humidity
    int  humidity = sisensor.getHumidityPercent();


    #ifdef MY_DEBUG
      Serial.print(F("Temperature SI7020 = "));
      Serial.print(temperature);
      Serial.println(F(" *C"));

      Serial.print(F("Humidity SI7020 = "));
      Serial.print(humidity);
      Serial.println(F(" %"));
    #endif

    // send temperature reading
    if (temperature != lastTemperature)
    {
      send(msgTemperature.set(temperature, 1));
      wait(WAIT_BETWEEN_SEND, C_INTERNAL, I_TIME); // Wait before next message send
      lastTemperature = temperature;
    }

    // send humidity reading
    if (humidity != lastHumidity)
    {
      send(msgHumidity.set(humidity, 0));
      wait(WAIT_BETWEEN_SEND, C_INTERNAL, I_TIME); // Wait before next message send
      lastHumidity = humidity;
    }

    // Rainbucket reading
    if (gotTime == true) {

      // let's constantly check to see if the rain in the past rainWindow hours is greater than rainSensorThreshold
      int measure = 0; // Check to see if we need to show sensor tripped in this block
      for (int i = 0; i < rainWindow; i++)
      {
        measure += rainBucket [i];
        if (measure != lastMeasure)
        {
          //      DEBUG_PRINT(F("measure value (total rainBucket within rainWindow): "));
          //      DEBUG_PRINTLN(measure);
          lastMeasure = measure;
        }
      }
      state = (measure >= (rainSensorThreshold * 100));

      // send rain tripped
      if (state != oldState)
      {
        //send(msgTripped.set(state));
        #ifdef MY_DEBUG
          Serial.print(F("New Sensor State... Sensor: "));
          Serial.println(state ? "Tripped" : "Not Tripped");
        #endif
        oldState = state;
      }

      unsigned long tipDelay = now() - lastRainTime;
      if (wasTippedBuffer) // if was tipped, then update the 24hour total and transmit to controller
      {
        #ifdef MY_DEBUG
          Serial.println(F("Sensor Tipped"));
          Serial.print(F("rainBucket [0] value: "));
          Serial.println(rainBucket [0]);
        #endif
        send(msgRain.set((float)rainTotal(currentHour) / 100, 1)); //Calculate the total rain for the day
        wait(WAIT_BETWEEN_SEND, C_INTERNAL, I_TIME); // Wait before next message send
        send(msgPrefix1.set("mm/h"));  // Set custom unit.
        wait(WAIT_BETWEEN_SEND, C_INTERNAL, I_TIME); // Wait before next message send
        wasTippedBuffer--;
        rainRate = ((oneHour) / tipDelay);

        // send rain rate
        if (rainRate != lastRainRate)
        {
          send(msgRainRate.set(rainRate, 1));
          wait(WAIT_BETWEEN_SEND, C_INTERNAL, I_TIME); // Wait before next message send
          #ifdef MY_DEBUG
            Serial.print(F("RainRate= "));
            Serial.println(rainRate);
          #endif
          lastRainRate = rainRate;
        }
        lastRainTime = lastTipTimeRTC;
      }

      currentHour = hour();
      if (currentHour != lastHour)  //  we have new hour , do the math
      {
        send(msgRain.set((float)rainTotal(currentHour) / 100, 1)); // send today's rainfall
        wait(WAIT_BETWEEN_SEND, C_INTERNAL, I_TIME); // Wait before next message send
        saveState(eepromIndex, highByte(rainBucket[0]));
        saveState(eepromIndex + 1, lowByte(rainBucket[0]));
        #ifdef MY_DEBUG
          Serial.println(F("One hour elapsed."));
          Serial.print(F("Saving rainBucket[0] to eeprom. rainBucket[0] = "));
          Serial.println(rainBucket[0]);
        #endif
        for (int i = RAIN_BUCKET_SIZE - 1; i >= 0; i--)//cascade an hour of values back into the array
        {
          rainBucket [i + 1] = rainBucket [i];
        }
        //request(CHILD_ID_TRIPPED_INDICATOR, V_VAR1);
        //request(CHILD_ID_TRIPPED_INDICATOR, V_VAR2);
        rainBucket[0] = 0;
        eepromIndex = eepromIndex + 2;
        if (eepromIndex > EEPROM_BUFFER_LOCATION + E_BUFFER_LENGTH)
        {
          eepromIndex = EEPROM_BUFFER_LOCATION;
        }
        #ifdef MY_DEBUG
          Serial.print(F("Writing to EEPROM.  Index: "));
          Serial.println(eepromIndex);
        #endif
        saveState(eepromIndex, 0xFE);
        saveState(eepromIndex + 1, 0xFE);
        gotTime = false;
        requestTime(); // sync the time every hour
        #ifdef MY_DEBUG
          Serial.println(F("Requesting time for this hour"));
        #endif
        transmitRainData();
        rainRate = 0;
        send(msgRainRate.set(rainRate, 1));
        wait(WAIT_BETWEEN_SEND, C_INTERNAL, I_TIME); // Wait before next message send
        #ifdef MY_DEBUG
          Serial.println(F("Sending rainRate is 0 to controller"));
        #endif
        lastHour = hour();
      }
    }
  } else {
    #ifdef MY_DEBUG
      Serial.println(F("Measurring pressure"));
    #endif
    // get the pressure reading but don't send data
    pressure = 0 ;
    bmp.readTemperature();
    wait(1000, C_INTERNAL, I_TIME);
    pressure = bmp.readSealevelPressure(ALTITUDE) / 100.0;
    forecast = sample(pressure);
  }
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

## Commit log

2017-09-11 Updated code, added PCB
    [WeatherStation PCB.fzz]
2017-09-11 added PCB preview
2017-09-11 Updated Docs
    [meteostanica lievik.ipt, meteostanica lievik.stl, moisture meter holder.ipt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]

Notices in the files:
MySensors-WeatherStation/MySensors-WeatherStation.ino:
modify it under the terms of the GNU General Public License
